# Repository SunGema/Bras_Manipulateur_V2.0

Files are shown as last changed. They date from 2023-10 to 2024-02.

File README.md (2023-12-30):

# Bras_Manipulateur_V2.0

Ceci est le projet de 5e année portée par l'ENSIBS : Le bras manipulateur V2.0
Ce projet est réalisé pour la chaire MAD permettant aux personnes à mobilité réduite de réaliser des tâches complexes de manipulation (typiquement en cuisine).

Ce projet rentre dans le cadre du 2nd axe de la Chaire MAD : Permettre les gestes du quotidiens en toute sécurité.

Pour ce projet l'équipe est constitué de :
  - Yann (CHEF)
  - Matthieu (Executant)
  - Hugues-Edouard (Executant)
  - Louis (Executant)
  - Pape (Executant)

NEW Partie Hard : 

ATTENTION : Certains fichiers de l'assemblage ont bougé au sein des dossiers il faudra les retrouver les fichiers concernés lors de l'ouverture de l'assemblage

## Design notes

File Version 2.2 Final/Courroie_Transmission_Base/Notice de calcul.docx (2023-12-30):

Projet Mécatronique

Heude Matthieu Simon Yann

01/12/2023

Notice de calcul

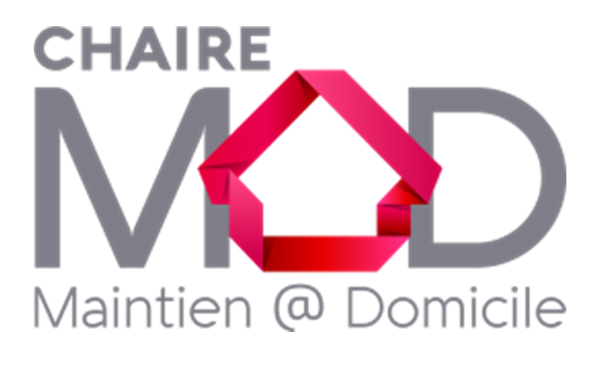
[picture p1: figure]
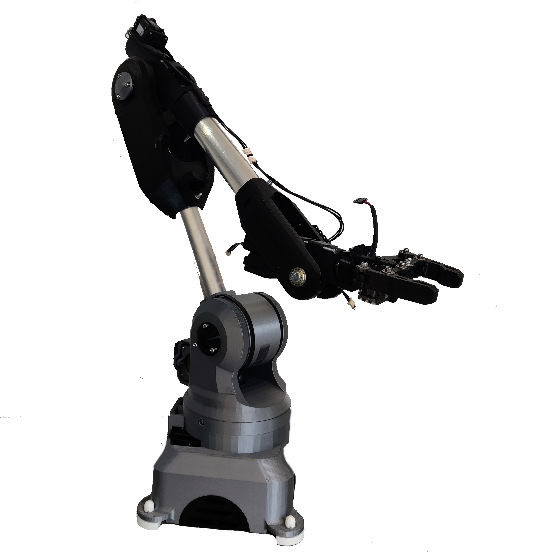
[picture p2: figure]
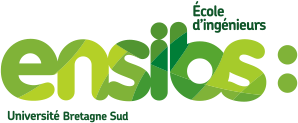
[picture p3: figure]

# Table des figures

# Introduction

Le bras manipulateur de la chaire Maintien à Domicile fait l’objet d’un projet de 5e année en mécatronique. En effet ce bras est sujet à des réparations dont le but est de le rendre opérationnel pour exécuter des programmes et réaliser des scénarios où ce bras assiste une personne à mobilité réduite dans des tâches quotidiennes (comme la cuisine).

Le principal problème de ce bras est le sous-dimensionnement de quelques parties qui ont finis par être déformées plastiquement voire cassées comme c’est le cas des pignons sur la Figure 1.

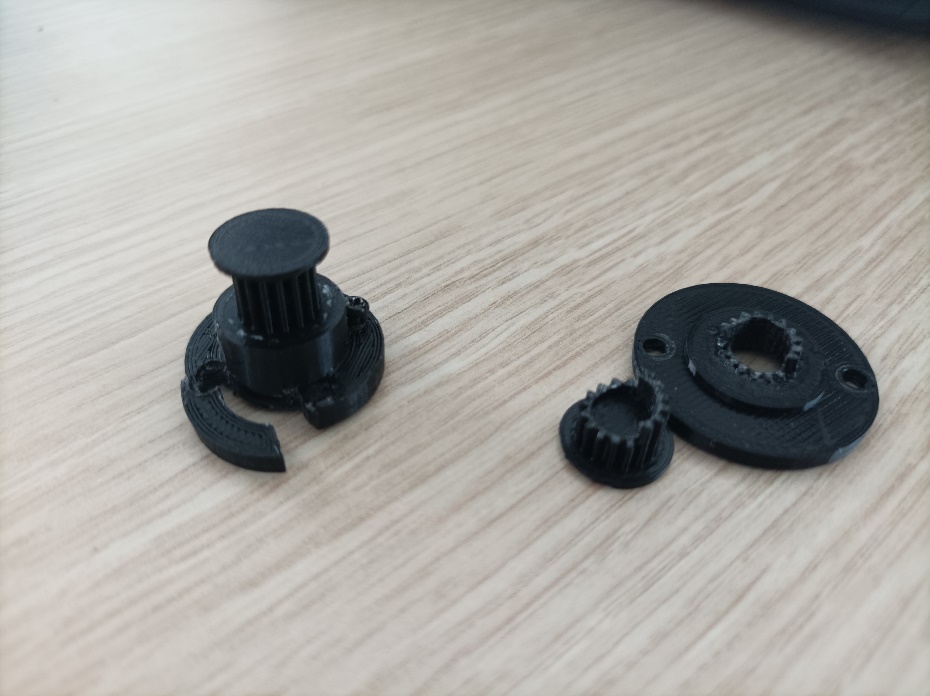
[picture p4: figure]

Figure 1 : Pignons sous-dimensionnés

Ces pignons sont pourtant essentiels dans le fonctionnement du robot car ils permettent le mouvement des différentes articulations de ce dernier par l’intermédiaire de courroies 2GT liées aux articulations et aux moteurs. C’est pourquoi nous avons décidé d’opter pour des pignons en métal (Figure 2) autrement appelé roue synchrone 2GT compatible avec les courroies utilisées dans ce bras manipulateur

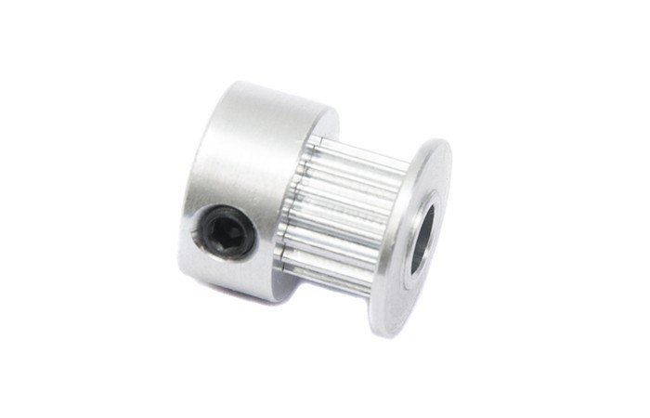
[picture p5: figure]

Figure 2 : Roue synchrone 2GT

Or les moteurs du bras manipulateur sont des moteurs Dynamixel semblable à celui de la Figure 3 qui ne présente pas d’axe moteur pour lier la roue synchrone au moteur

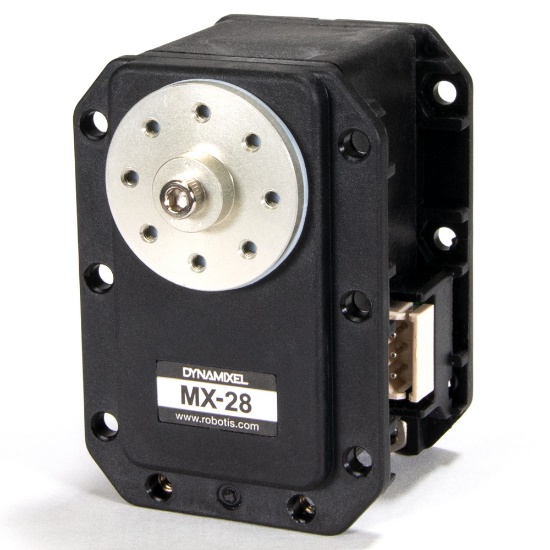
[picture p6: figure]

Figure 3 : Moteur Dynamixel

Ainsi il a été décidé de concevoir une interface, une pièce liant ces deux parties. Cependant pour éviter de faire de nouveau face aux problèmes de la Figure 1 ou encore pour éviter toute casse moteur, cette notice de calcul permet de comprendre l’intérêt de cette pièce interface, comment a-t-elle été conçue et la manière dont cette solution fait face à tous les problèmes ainsi qu’aux contraintes déjà présentes sur le bras manipulateur. Dans un premier temps nous vous expliquerons la pièce en question puis nous réaliserons les calculs et les simulations nécessaires pour montrer la viabilité de cette solution.

# Présentation de la pièce

La pièce modélisée est un élément qui fait l’interface entre une roue synchrone 2GT (Figure 2) et un moteur Dynamixel avec une base (Figure 3). Cette pièce possède un trou permettant d’accueillir le pignon. Une roue synchrone possède des trous filetés afin d’y insérer une vis pouvant faire pression sur un axe. Ici l’axe n’étant pas présent, nous utilisons ces trous pour lier la roue synchrone à cette pièce interface via des vis M4. Ensuite des trous traversant la pièce permettant via des vis M2,5 de se fixer à 4 trous sur les 8 que propose la base du moteur dynamixel (Figure 4).

Ainsi dans cette configuration, le pignon est lié à la pièce et la pièce est lié au moteur par conséquent nous sommes parvenus à lier le pignon au moteur. A première vue, le pignon en métal permet de solutionner le problème de casse des pignons face aux tensions des courroie. Reste à savoir si la pièce faisant interface peut également supporter ces efforts. Cette étude est disponible dans la partie II. Il faut aussi noter que les efforts peuvent être important pour le moteur. C’est d’autant plus le cas lorsque l’on déplace l’effort sur l’axe au plus loin du moteur l’étude sur l’effort radiale est disponible dans la partie I.

# Partie I - Calcul d’effort sur le pignon

# Partie II – Etude élément finis

# Conclusion de l’étude

Heude Matthieu Simon Yann 01/12/23 Notice de calcul

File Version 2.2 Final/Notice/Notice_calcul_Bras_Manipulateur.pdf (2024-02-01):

# Projet Mécatronique

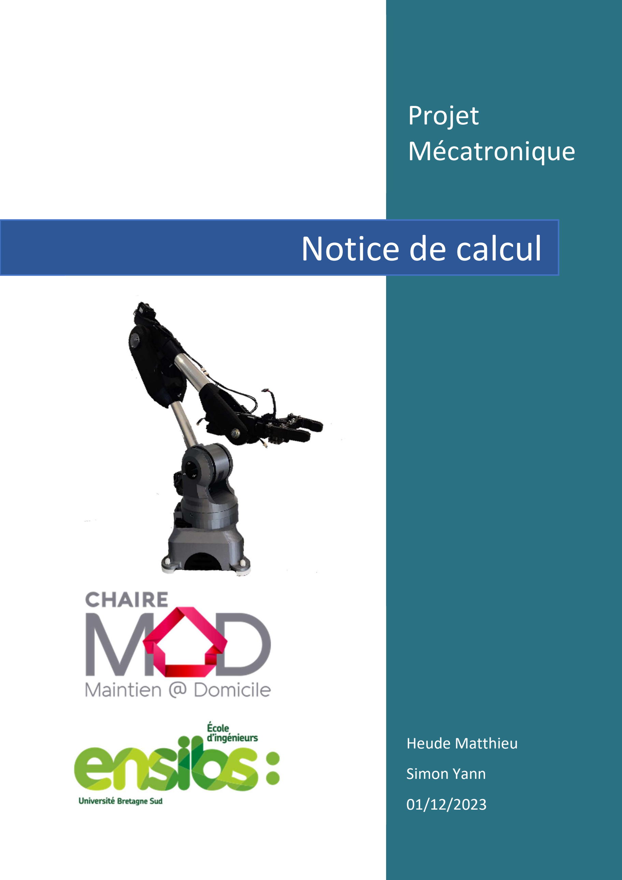
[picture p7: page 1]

## Heude Matthieu Simon Yann

01/12/2023

# Notice de calcul

HEUDE MATTHIEU SIMON YANN 01/12/23

NOTICE DE CALCUL

1

## Table des matières

Table des figures | 1
Introducon | 2
Présentaon de la pièce | 4
Pare I - Calcul d’effort sur le pignon | 5
Effort radial maximal | 5
Déterminaon de l’effort | 6
Conclusion | 6
Pare II – Étude élément finis | 7
Modèle élément finis | 7
Type de problème | 7
Symétrie et simplificaon | 7
Caractérisques matériaux | 7
Résoluon | 7
Condions aux limites et chargements | 8
Maillage | 8
Résultats | 8
Conclusion | 8
Conclusion de l’étude | 8

## Table des figures

Figure 1 : Pignons sous-dimensionnés | 2
Figure 2 : Roue synchrone 2 GT | 3
Figure 3 : Moteur Dynamixel | 3
Figure 4 : Pièce interface entre pignon et moteur | 4
Figure 5 : Effort maximal supporté par le moteur | 5
Figure 6 : Mesure de la tension de la courroie | 6

2

## Introducon

Le bras manipulateur de la chaire Mainen à Domicile fait l’objet d’un projet de 5e année en mécatronique. En effet, ce bras est sujet à des réparaons dont le but est de le rendre opéraonnel pour exécuter des programmes et réaliser des scénarios où ce bras assiste une personne à mobilité réduite dans des tâches quodiennes (comme la cuisine).

Le principal problème de ce bras est le sous-dimensionnement de quelques pares qui ont fini par être déformées plasquement voire cassées comme c’est le cas des pignons sur la Figure 1.

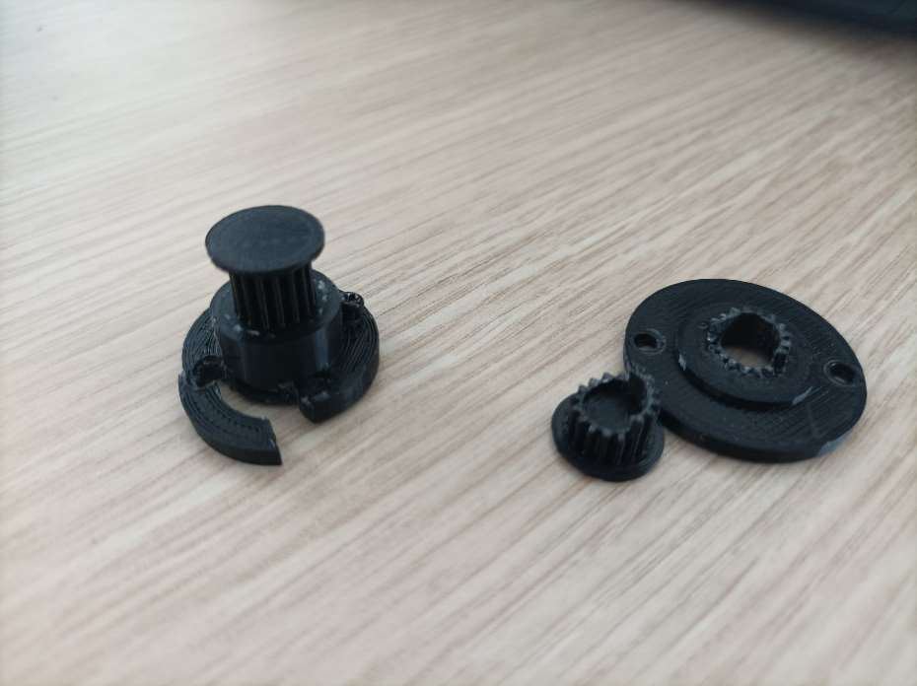
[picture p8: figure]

Figure 1 : Pignons sous-dimensionnés

Ces pignons sont pourtant essenels dans le fonconnement du robot, car ils permeent le mouvement des différentes arculaons de ce dernier par l’intermédiaire de courroies 2 GT liées aux arculaons et aux moteurs. C’est pourquoi nous avons décidé d’opter pour des pignons en métal (Figure 2.) autrement appelé roue synchrone 2 GT compable avec les courroies ulisées dans ce bras manipulateur.

3

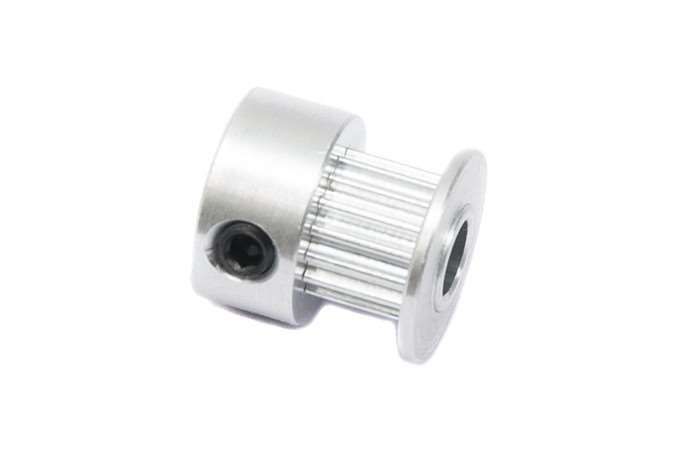
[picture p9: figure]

Figure 2 : Roue synchrone 2 GT

Or les moteurs du bras manipulateur sont des moteurs Dynamixel semblables à celui de la Figure 3 qui ne présente pas d’axe moteur pour lier la roue synchrone au moteur

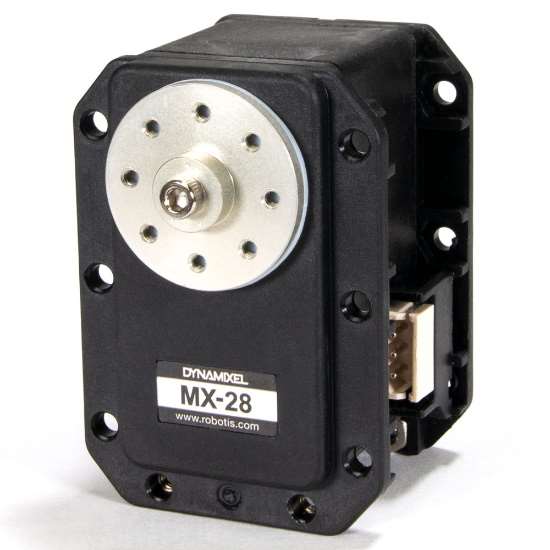
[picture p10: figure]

Figure 3 : Moteur Dynamixel

Ainsi, il a été décidé de concevoir une interface, une pièce liant ces deux pares. Cependant pour se dispenser de faire de nouveau face aux problèmes de la Figure 1 ou encore pour éviter toute casse moteur, cee noce de calcul permet de comprendre l’intérêt de cee pièce interface, comment a-t-elle été conçue et la manière dont cee soluon fait face à tous les problèmes ainsi qu’aux contraintes déjà présentes sur le bras manipulateur. Dans un premier temps, nous vous expliquerons la pièce en queson puis nous réaliserons les calculs et les simulaons nécessaires pour montrer la viabilité de cee soluon.

4

## Présentaon de la pièce

La pièce modélisée est un élément qui fait l’interface entre une roue synchrone 2 GT (Figure 2) et un moteur Dynamixel avec une base (Figure 3). Cee pièce possède un trou permeant d’accueillir le pignon. Une roue synchrone possède des trous filetés afin d’y insérer une vis pouvant faire pression sur un axe. Ici, l’axe n’étant pas présent, nous ulisons ces trous pour lier la roue synchrone à cee pièce interface via des vis M4. Ensuite des trous traversant la pièce permeant via des vis M2,5 de se fixer à 4 trous sur les 8 que propose la base du moteur Dynamixel (Figure 4.).

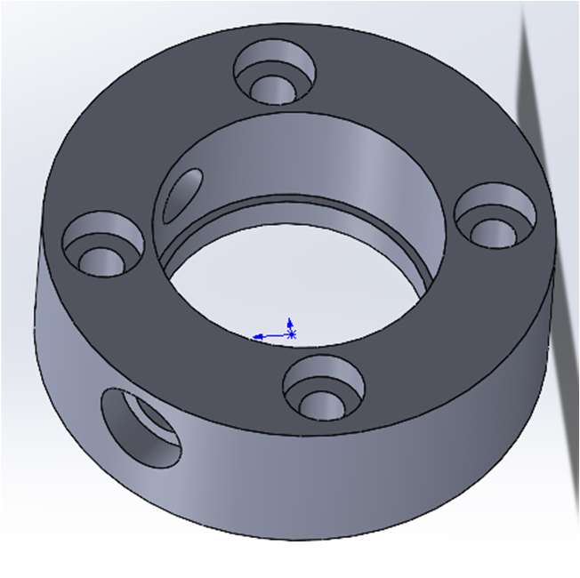
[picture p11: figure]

Figure 4 : Pièce interface entre pignon et moteur

Ainsi, dans cee configuraon, le pignon est lié à la pièce et la pièce est liée au moteur par conséquent, nous sommes parvenus à lier le pignon au moteur. À première vue, le pignon en métal permet de soluonner le problème de casse des pignons face aux tensions des courroies. Reste à savoir si la pièce faisant l'interface peut également supporter ces efforts. Cee étude est disponible dans la pare II. Il est aussi nécessaire de noter que les efforts peuvent être considérables pour le moteur. C’est d’autant plus le cas lorsque l’on déplace l’effort sur l’axe au plus loin du moteur. L’étude sur l’effort radiale est disponible dans la pare I.

5

## Pare I - Calcul d’effort sur le pignon

La déterminaon de l’effort radial et les limites du moteur est l’objecf de l’étude. Effort radial maximal

D’après la documentaon du moteur Dynamixel, l’effort maximal radial supporté est de

### 40 N à 10 mm de sa base comme décrit la Figure 5 : Effort maximal supporté par le

moteurFigure 5

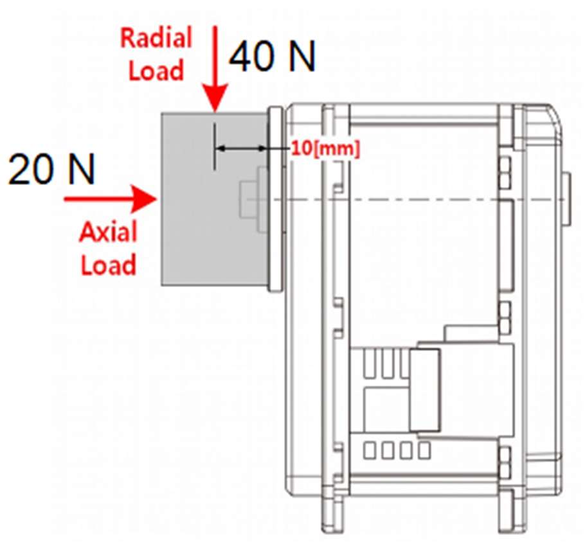
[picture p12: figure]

Figure 5 : Effort maximal supporté par le moteur

La tension de la courroie provoque une charge radiale appliquée à la poulie qui est reliée à ce moteur. Cet effort pouvait être supporté par le moteur Dynamixel, mais notre soluon de pièce interface entre la poulie et le moteur (Figure 4.) rehausse la poulie et donc écarte le point d’applicaon de l’effort radial de la base moteur. Le moment ainsi généré peut provoquer une casse-moteur car ce dernier ne serait pas en état de supporter un effort de même intensité sur une longueur plus grande. Ainsi, il est primordial de déterminer la nouvelle limite d’effort radiale à ne pas dépasser.

Soit F = 40 N, l’effort radial à D = 10 mm de la base moteur
La pièce rehausse le point d’application de l’effort radial à D = 22 mm.

L’égalité des moments nous donne :

F × D = F× D (1)

D’après l’équation (1), l’effort maximal supporté à 22 mm de la base moteur est de 18,2 N

6

Déterminaon de l’effort

Le calcul de l’effort maximal a donné que la tension de courroie ne devait pas excéder les 18,2 N pour éviter la casse-moteur.

Pour s’assurer de cela, nous en sommes venus à mesurer la tension de la courroie à l’aide d’un dynamomètre. Nous avons reré le moteur puis placé sur la courroie, le dynamomètre. Ensuite, nous avons tendu la courroie au même niveau que la poulie (voir Figure 6.).

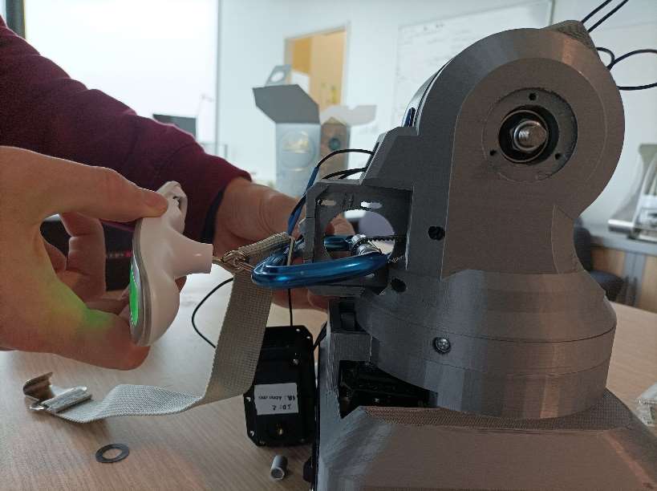
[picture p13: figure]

Figure 6 : Mesure de la tension de la courroie
La tension affichée sur le dynamomètre montre un effort d’environ 1 kg. Delà, nous pouvons esmer l’effort radial sur la poulie :

F = 1,5 × 9,81 = 14,7 N

D’après les résultats de la pare précédente, nous avons :

F < F

Conclusion

Dans cee première pare, l’effort radial maximal à prendre en compte a été revu en foncon de la soluon apportée aux problèmes de sous-dimensionnement (voir Figure 1). Nous pouvons dire que l’effort de tension de la courroie reste inférieur à cee nouvelle limite assurant que le moteur ne cédera pas face à l’effort radial exercé.

7

## Pare II – Étude élément finis

La déterminaon des contraintes au sein de la soluon choisie est l’objecf de l’étude.

Modèle élément finis

Type de problème

Le modèle ulisé dans cee pare est la pièce modélisée en CAO dans son enèreté dont nous avons réalisé l’importaon. Nous avons un modèle 3D déformable. La pièce est cylindrique de 28 mm de diamètre avec un trou de 16 mm de diamètre en son centre. La hauteur de cee pièce est de 9,5 mm et elle accueille 4 trous de vis pour se fixer sur le moteur ainsi que deux trous de vis plus important sur les côtés pour fixer la poulie (voir Figure 4.)

Symétrie et simplificaon

Sur cee pièce, il n’y a pas de plan ou d’axe de symétrie à exploiter pour simplifier le modèle.

Caractérisques matériaux

Le matériau avec lequel la pièce a été fabriquée est un PLA avec un module d’Young de 935 MPa et une résistance élasque de 50 MPa.

Résoluon

La résoluon du calcul est staque, car nous nous plaçons dans une posion de la pièce au cours de la rotaon du moteur. Ainsi, il n’y a pas de mouvement. La réponse de ce calcul est linéaire, car nous nous plaçons dans le domaine des petes déformaons.

8

Condions aux limites et chargements (Coming soon)

Maillage
(Coming soon)

Résultats
(Coming soon)

Conclusion
(Coming soon)

## Conclusion de l’étude

(Coming soon)

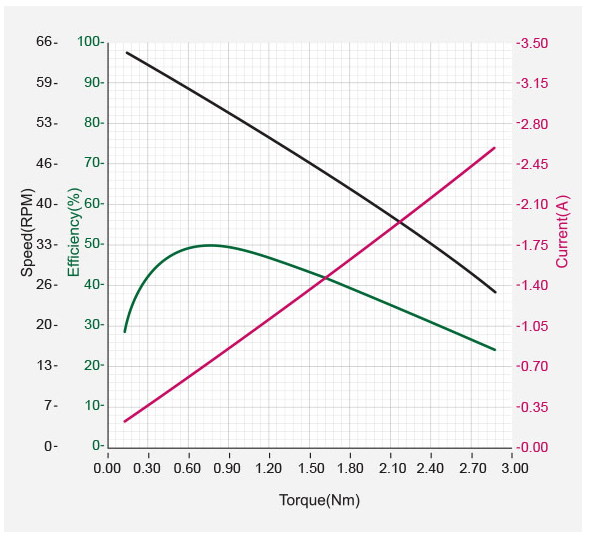
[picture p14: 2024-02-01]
Version 2.2 Final/Notice/Courbe_Moteur.png

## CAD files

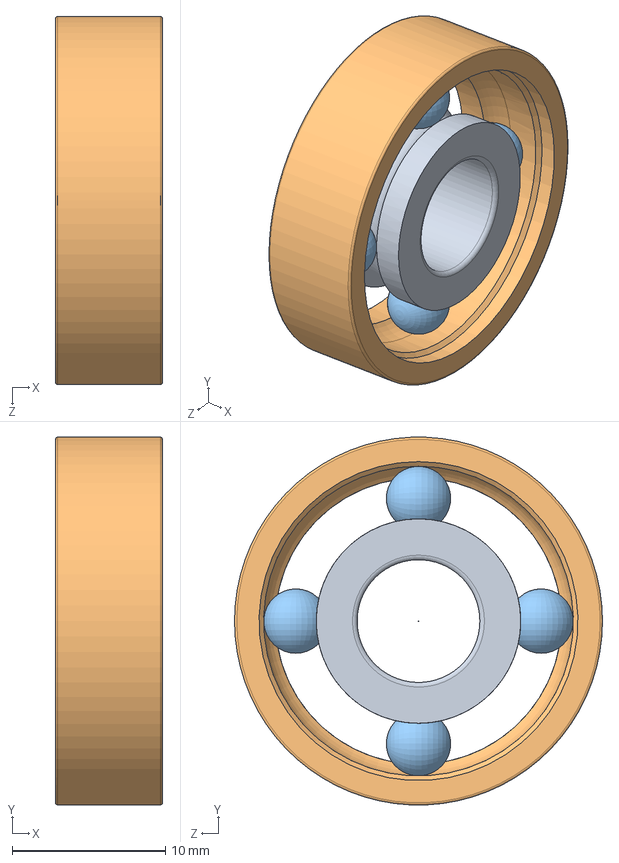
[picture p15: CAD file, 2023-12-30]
Version 2.2 Final/143539572-7-bearing_e_8/bearing_e_8.SLDASM
7.00 x 24.0 x 24.0 mm
bearing_e_8_01
bearing_e_8_02
bearing_e_8_03

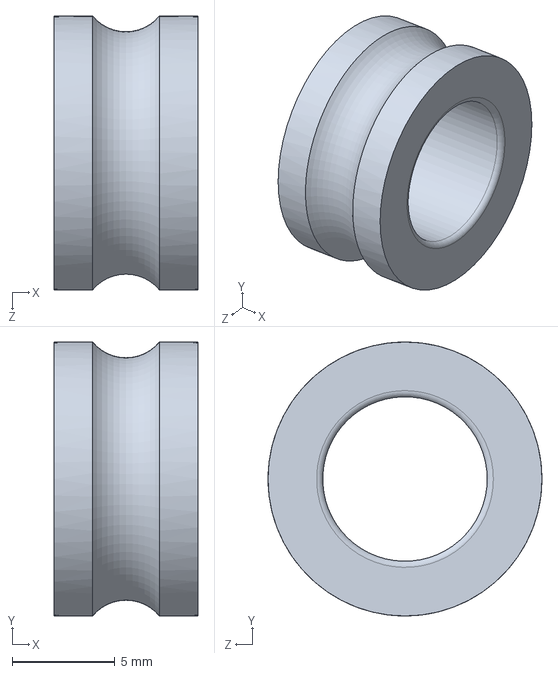
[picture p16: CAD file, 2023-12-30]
Version 2.2 Final/143539572-7-bearing_e_8/bearing_e_8_01.SLDPRT
7.00 x 13.3 x 13.3 mm

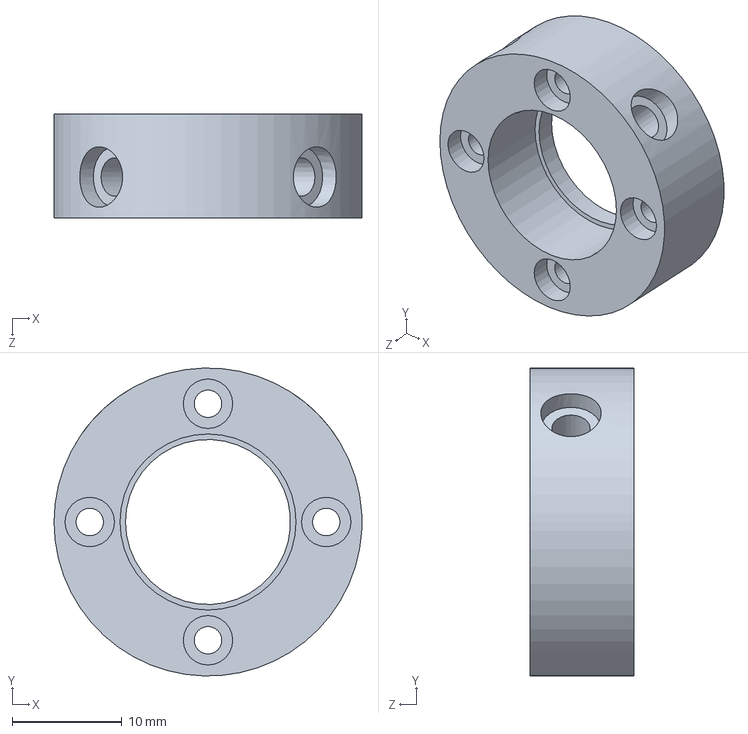
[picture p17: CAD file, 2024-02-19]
Version 2.2 Final/Courroie_Transmission_Base/Support roue synchrone 2.SLDPRT
28.0 x 28.0 x 9.50 mm

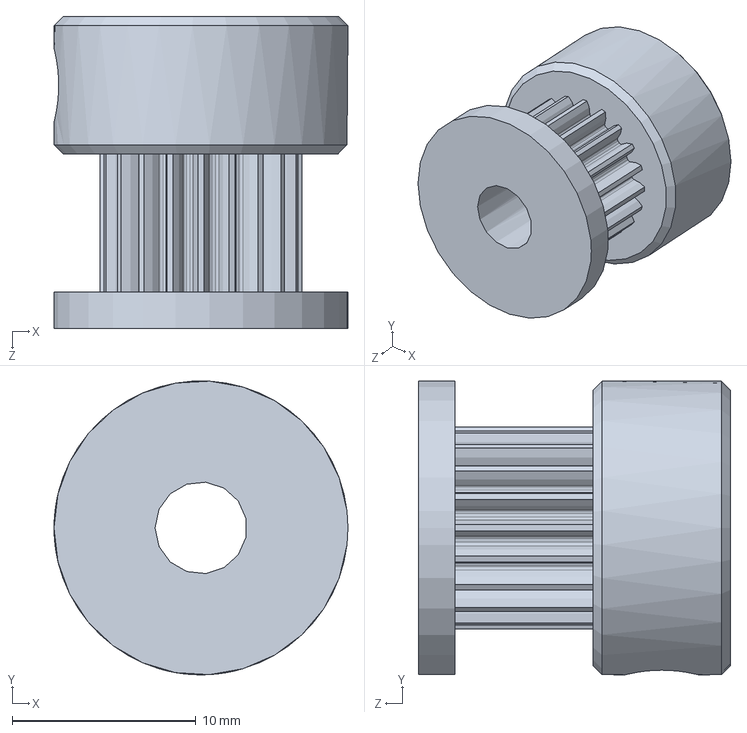
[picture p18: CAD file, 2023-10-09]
Version 2.2 Final/Gear/Roue syncrhone 2GT 20 dents.SLDPRT
16.0 x 16.0 x 17.0 mm

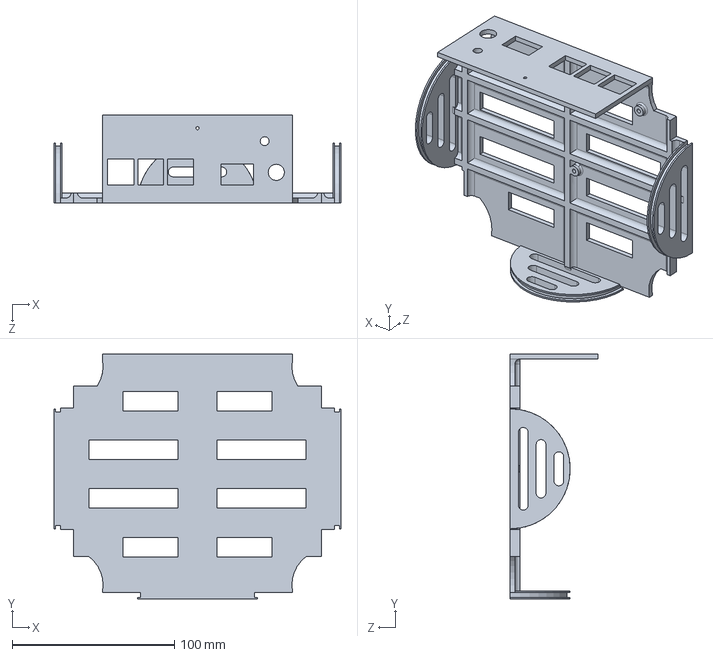
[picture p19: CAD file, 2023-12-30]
Version 2.2 Final/New_base/support_bas.SLDPRT
177.0 x 151.0 x 54.0 mm

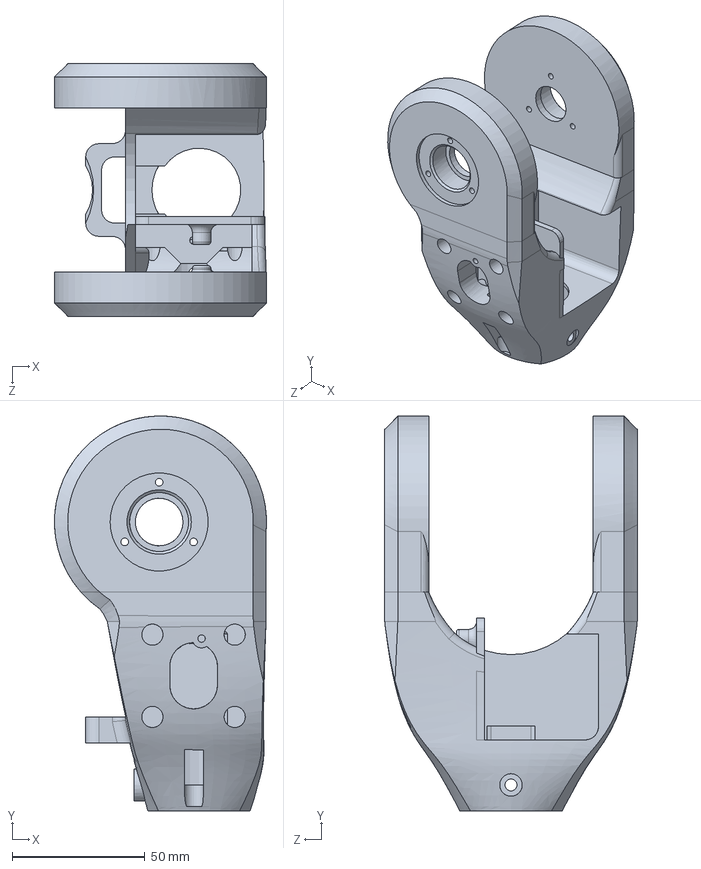
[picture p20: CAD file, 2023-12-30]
Version 2.2 Final/New_elbow/My_arm_top/my_arm_top.SLDPRT
80.0 x 149.0 x 95.4 mm

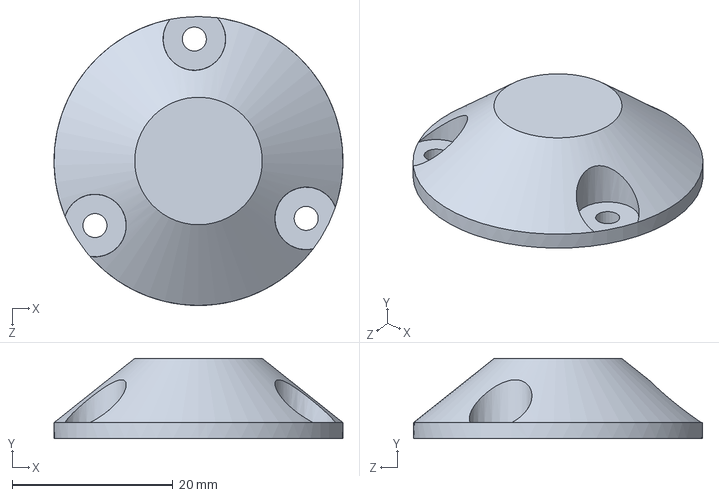
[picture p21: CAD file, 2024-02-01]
Version 2.2 Final/New_elbow/my_cache_elbow.SLDPRT
36.0 x 10.0 x 36.0 mm

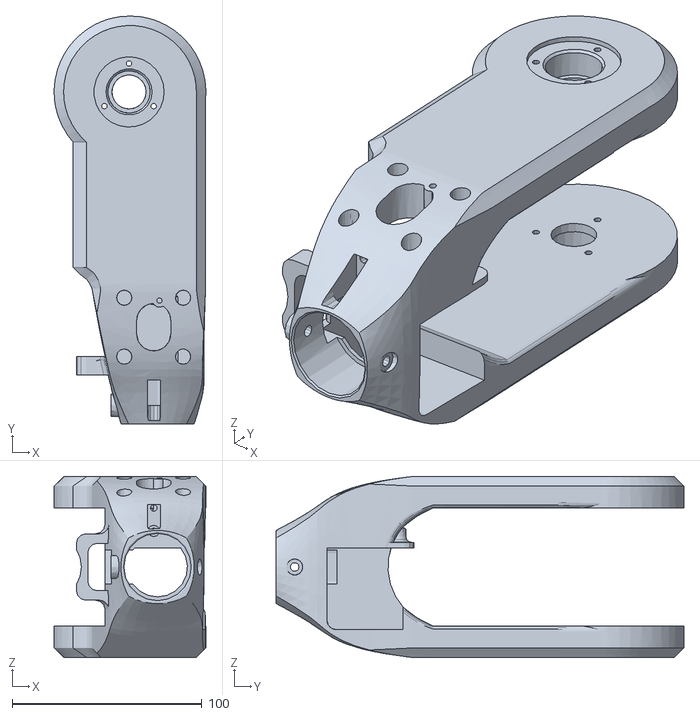
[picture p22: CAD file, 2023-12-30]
Version 2.2 Final/New_elbow/STL/my_arm_top_final.STL
80.0 x 215.0 x 95.4

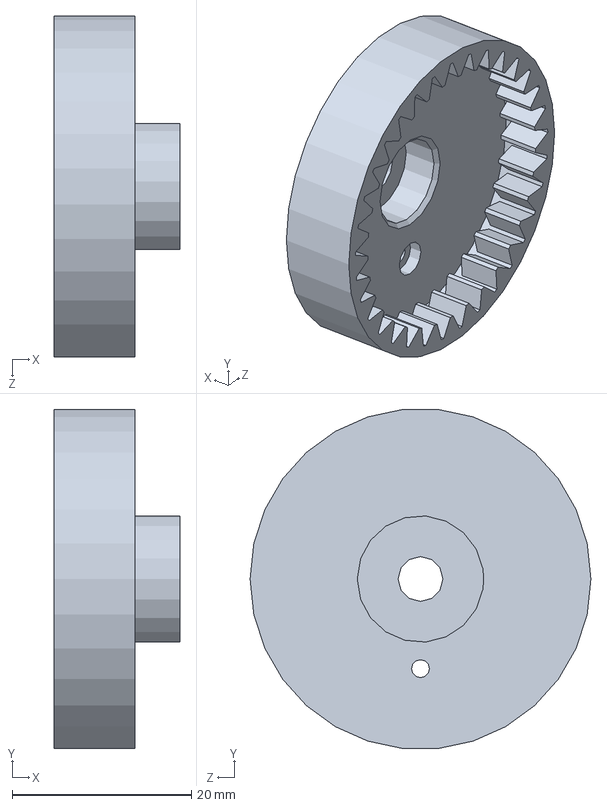
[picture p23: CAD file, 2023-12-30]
Version 2.2 Final/New_elbow/Train_epicycloidal/engrenage_couronne_2.SLDPRT
14.0 x 37.8 x 38.0 mm

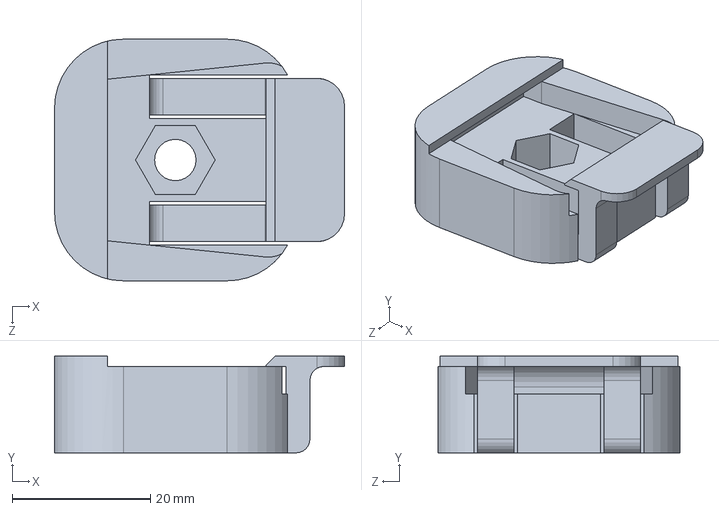
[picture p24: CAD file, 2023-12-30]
Version 2.2 Final/New_hand/my_hand.SLDPRT
42.0 x 14.0 x 35.0 mm

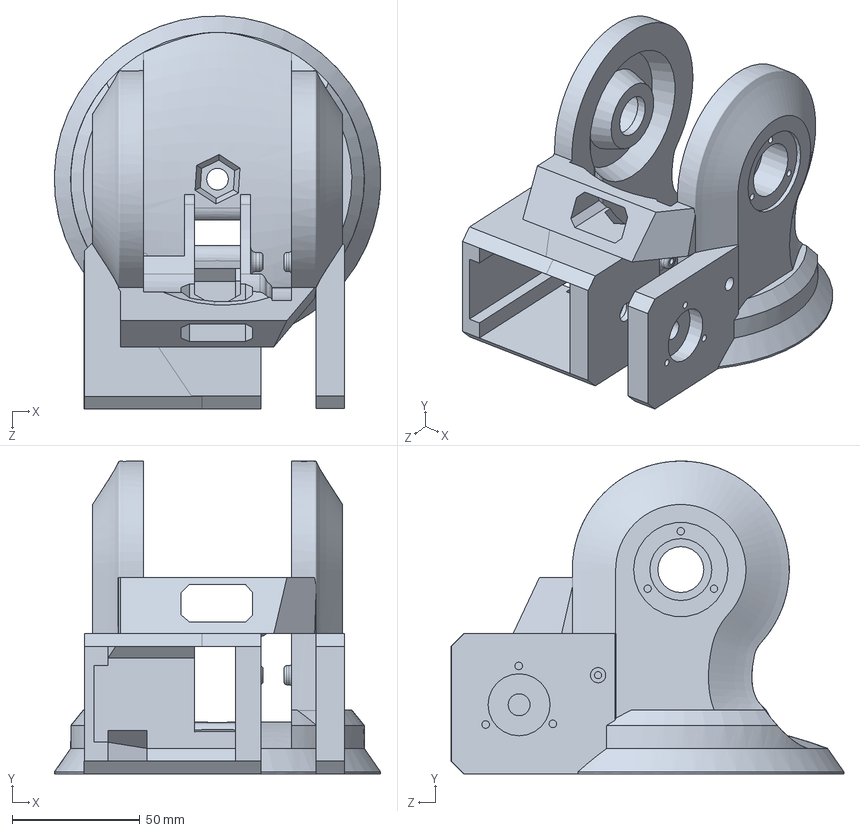
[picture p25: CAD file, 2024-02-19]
Version 2.2 Final/New_shoulder/my_shoulder.SLDPRT
127.8 x 122.5 x 153.9 mm

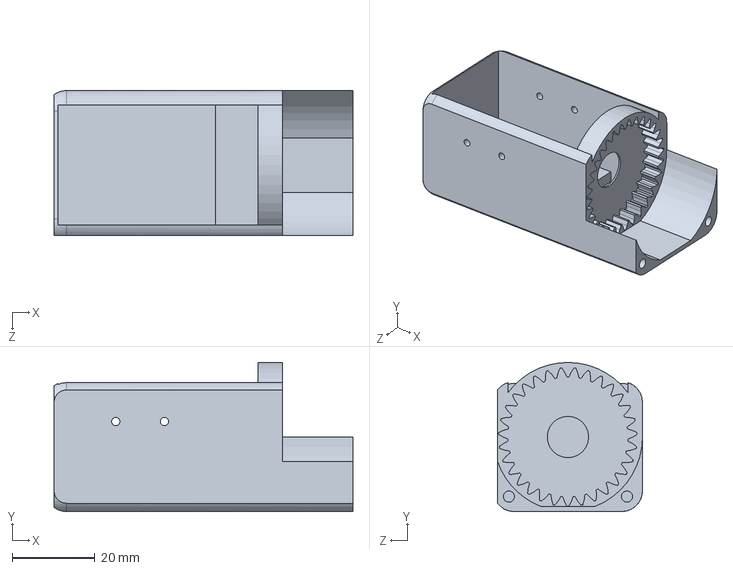
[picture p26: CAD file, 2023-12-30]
Version 2.2 Final/New_wirst/berceau_moteur.SLDPRT
72.2 x 36.0 x 35.0 mm

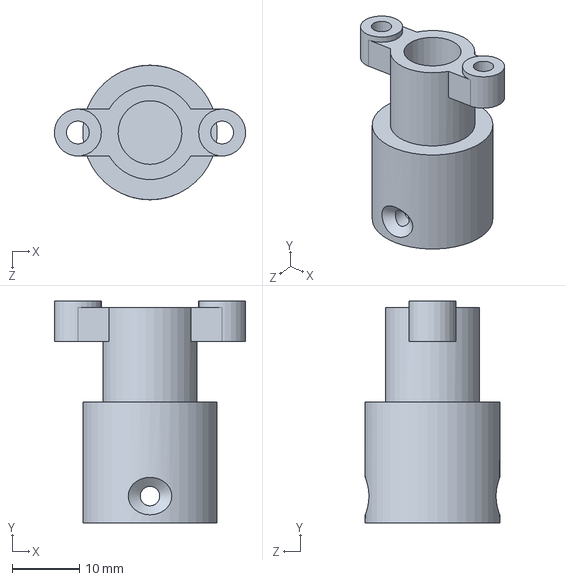
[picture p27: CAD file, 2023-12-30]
Version 2.2 Final/New_wirst/Train_epicycloidal/planetaire_fin_berceau.SLDPRT
28.4 x 33.0 x 20.0 mm

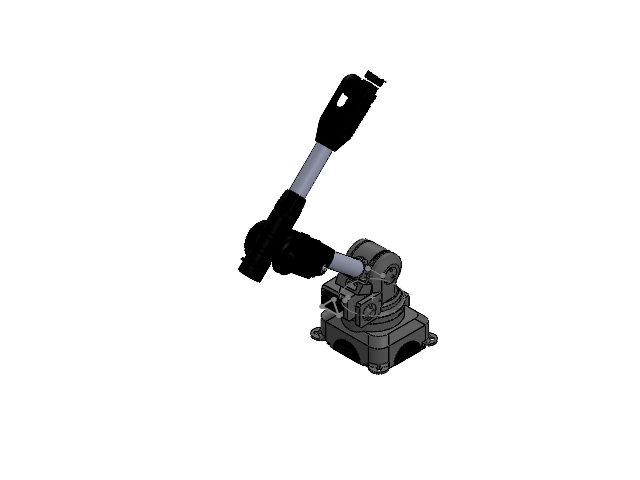
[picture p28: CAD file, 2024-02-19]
Version 2.2 Final/Assemblage_HANDrew.SLDASM
my_base
support_bas
my_base_bearing_support
my_shoulder
my_arm_bottom
tube_bottom
my_bottom_arm
my_elbow
tube_top
my_fore_arm_top
berceau_axe
berceau_moteur
my_hand
Dynamixe_motor x 2
Support roue synchrone 2
Roue syncrhone 2GT 20 dents x 2
bearing_e_8_01 x 7
bearing_e_8_02 x 7
bearing_e_8_03 x 7
Tige8x95 x 2
Tige8x45
Tige8x60
my_cache_shoulder x 2
my_cache_elbow x 3
Arm_top_V4

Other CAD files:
Version2.1/Assemblage_HANDrew.SLDASM
Version 2.2 Final/Nouvelle pièce/Assemblage_Notice.SLDASM
Version 2.2 Final/Nouvelle pièce/Assem2.SLDASM
Version 2.2 Final/143539572-7-bearing_e_8/bearing_e_8_02.SLDPRT
Version 2.2 Final/143539572-7-bearing_e_8/bearing_e_8_03.SLDPRT
Version 2.2 Final/Courroie_Transmission_Base/Arm_top_V3.SLDPRT
Version 2.2 Final/Courroie_Transmission_Base/Support roue synchrone.SLDPRT
Version 2.2 Final/Dynamixe_motor.SLDPRT
Version 2.2 Final/New_base/STL/engrenage_moteur.STL
Version 2.2 Final/New_base/STL/fixation_d.STL
Version 2.2 Final/New_base/STL/fixation_g.STL
Version 2.2 Final/New_base/STL/my_base.STL
Version 2.2 Final/New_base/STL/my_base_bearing_support.STL
Version 2.2 Final/New_base/STL/support_bas.STL
Version 2.2 Final/New_base/STL/support_moteur_base.STL
Version 2.2 Final/New_base/engrenage_moteur.SLDPRT
Version 2.2 Final/New_base/fixation_d.SLDPRT
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

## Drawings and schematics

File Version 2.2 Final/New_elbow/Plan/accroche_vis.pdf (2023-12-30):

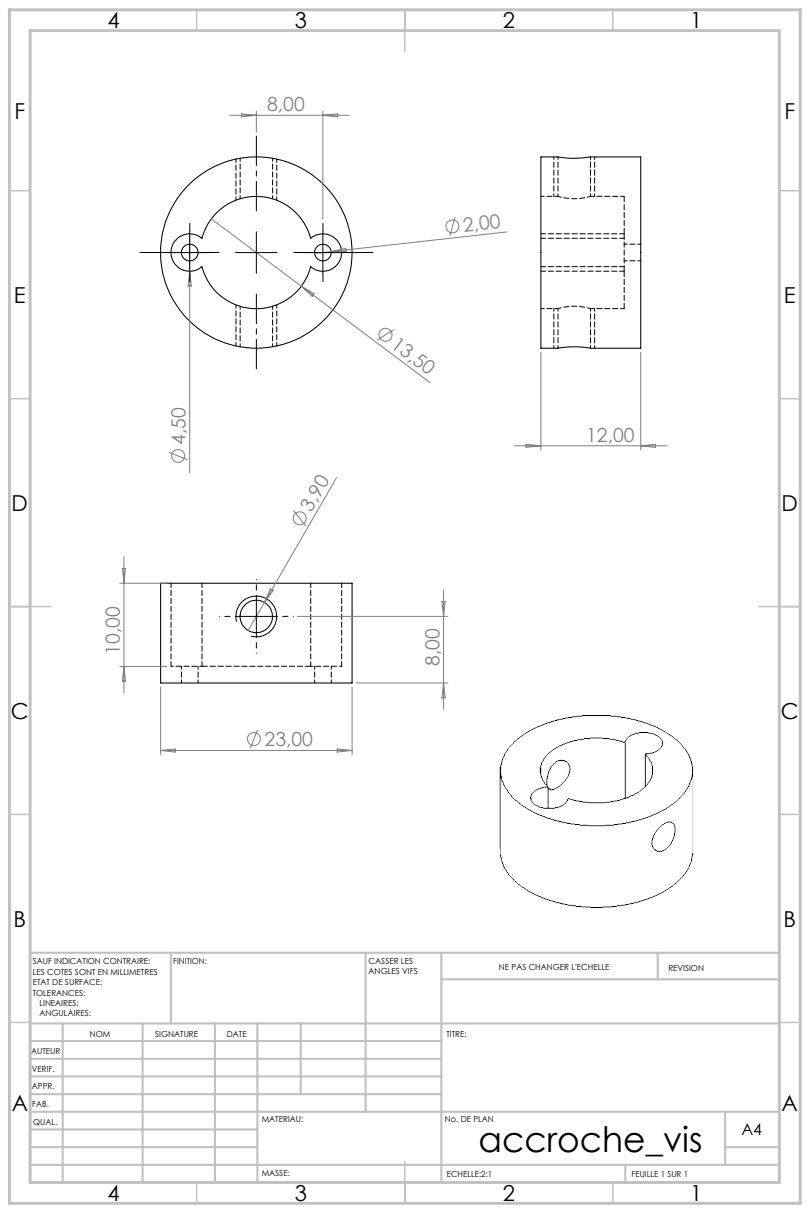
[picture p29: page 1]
FINITION:; CASSER LES; ANGLES VIFS; NE PAS CHANGER L'ECHELLE; REVISION; ECHELLE:2:1; FEUILLE 1 SUR 1

SAUF INDICATION CONTRAIRE:
LES COTES SONT EN MILLIMETRES
ETAT DE SURFACE:
TOLERANCES:
LINEAIRES:
ANGULAIRES:

NOM | SIGNATURE | DATE | | | | TITRE:

AUTEUR
VERIF.
APPR.
FAB.
QUAL. | | | | MATERIAU: | No. DE PLAN accroche_vis | A4

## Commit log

2023-10-09 Ajout engrenage base
    [Roue syncrhone 2GT 20 dents.SLDPRT]
2023-11-10 Ajout modélisation support roue synchrone
    [Support roue synchrone.SLDPRT, Support roue synchrone2.SLDPRT]
2023-11-22 Modification bras et support moteur bras
    [Arm_top_V3.SLDPRT, Support roue synchrone 2.SLDPRT, Support roue synchrone2.SLDPRT]
2023-12-30 Mise à jour CAO
    [Assemblage_HANDrew.SLDASM, Dynamixe_motor.SLDPRT, Tige8x25.SLDPRT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]
2024-02-01 Ajout de la version final de la CAO
    [Arm_top_V3.SLDPRT, Arm_top_V4.SLDPRT, Assem2.SLDASM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]
